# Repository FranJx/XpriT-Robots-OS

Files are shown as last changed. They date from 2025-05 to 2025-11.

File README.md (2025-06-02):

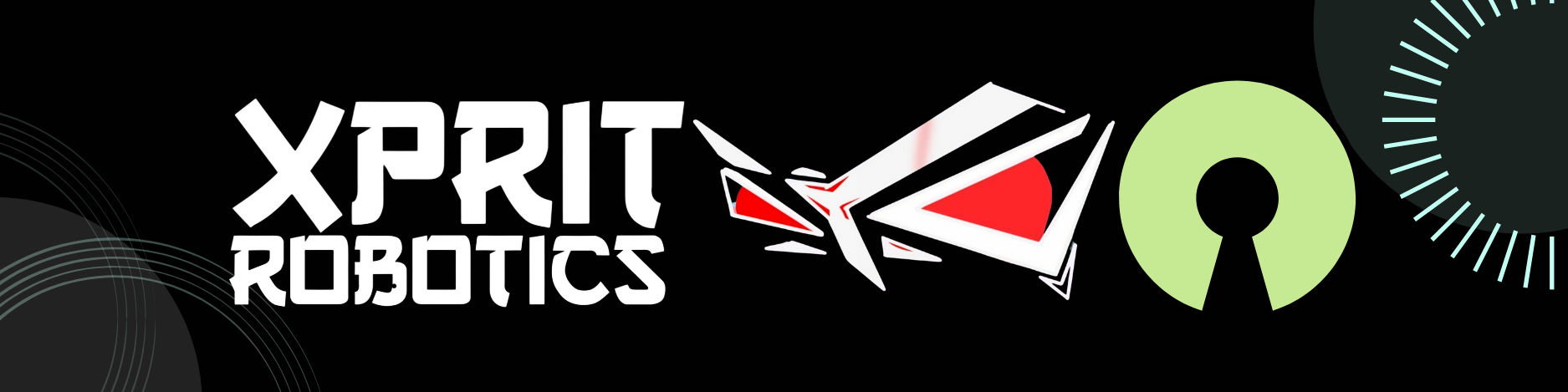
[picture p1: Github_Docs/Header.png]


# ⚙️ XpriT-Robots-OS

Welcome to **XpriT-Robots-OS**, the official collection of projects by **XpriT Robotics**, an Argentine team passionate about competitive, educational, and industrial robotics.

This repository is an open space where we share **complete robots**, **development boards**, **experimental designs**, and much more, aiming to **promote robotics** and inspire the next generation of innovators.

---

## 🌟 About Us

We are a group of young people from Misiones, Argentina, who found in robotics a way to learn, compete, teach, and dream. We founded **XpriT Robotics** with the purpose of taking our ideas beyond competitions, and today we’ve decided to open our designs to the world.

> “We dream of a future where every young person has access to build, make mistakes, gain experience... and share it.”

**Founder:** Franco Joaquín Aguirre Elizalde (Fran)  
🛠️ Self-taught | 🤖 WRO Champion | 🚀 Tech advocate

---

## 📁 Table of Contents

* [🤖 Featured Projects](#-featured-projects)
* [🔧 Boards and Open Hardware](#-boards-and-open-hardware)
* [📦 Repository Structure](#-repository-structure)
* [🧑‍💻 About the Team](#-about-the-team)
* [📸 Gallery and Videos](#-gallery-and-videos)
* [📜 Licenses](#-licenses)
* [📲 Social Media & Contact](#-social-media--contact)

---

## 🤖 Featured Projects

### 🐍 **Kōryū** — The Dragon of Wisdom
> This robot was developed to meet every need a minisumo might have. It's both fast and powerful, offering a perfect balance between speed and strength. Kōryū features an interactive OLED interface and multiple operating modes, including both Autonomous and RC (Remote Control) functionality.  
> In this project you'll find:
> - STL and SLDPRT of the chassis
> - Modular code with multi-mode support
> - Strategy breakdown and competition videos

---

### ⚔️ **XT Kaisei** — Precision in Minisumo Form

> Designed for **both beginners and professionals**, XT Kaisei delivers reliable performance in a compact and modular build. Its balanced sensor array and flexible motor support allow for efficient targeting, quick response, and seamless upgrades.  
> Includes:  
> - 98×98 mm 3D printable chassis  
> - 5x JS40F object sensors + 2x QTR1A line sensors  
> - Dual motor brackets for 050 or N20 formats

---

### 🛡️ **Titan-Core** — The XpriT All-Terrain Base

> Our foundational design for testing, learning, and continuous evolution.  
> Perfect for those who want to understand how a combat robot is built from scratch.  
> Contains:
> - Commented and modular code  
> - Custom PCB  
> - Step-by-step explanation

> ⚙️ More designs will be added: the XpriT collection never stops growing!

---

## 🔧 Boards and Open Hardware

This section includes our **custom-designed boards for competitive and educational robotics**:

- **XT-Prime**: ESP-based board with x3dipswitch, 9 GPIO( support I2C), 14v10A drivers x2 and 2A regulator  
- **XT-Pyramis**: A tiny Arduino-Based board for Autonomous Sumo( mini - micro) robots  
- **XP-SimDrive**: ESP32 + TB6612FNG Shield for simple RC robots

Each board includes:
- Gerber files + PDF  
- Component list  
- STL for protective casing  
- Schematics + technical documentation

---

## 🧑‍💻 About the Team

Team

We are **Franco**, **Marcelo**, **Franquito**, **Benja**, **Bauti**, and a group of collaborators, mentors, and friends who joined this journey. Our experience includes:

- 🥉 19th place at RoboChallenge Romania 2024  
- 🥇 National Champion at WRO Panama 2023  
- 🥉 3rd place at National Minisumo PRO 2023  
- 🏆 Multiple podiums at Robotic People Fest, Copa Robótica Misiones, and more

XpriT Robotics is more than a team: we are a growing and learning community.

---

## 📸 Gallery and Videos

Find photos of our robots and real demos at:

- 📷 Folder [`Images`](./Images)  
- 📽️ YouTube Channel [@xprit_robotics](https://youtube.com/@xprit_robotics)

> Subscribe so you don’t miss our next creations!

---

## 📜 Licenses

All our projects are released under licenses that allow free use with proper credit:

- **Code** → [MIT License](./LICENSE)  
- **3D designs, boards, and documentation** → [CC BY 4.0](https://creativecommons.org/licenses/by/4.0/)

> 🛡️ Use them, improve them — and don’t forget to credit us!

---

## 📲 Social Media & Contact

- 📸 Instagram: [@xprit_._robotics](https://www.instagram.com/xprit_robotics/)  
- ▶️ YouTube: [@xprit robotics](https://youtube.com/@xprit_robotics)  
- 📧 Contact: xpritrobotics@gmail.com

---

**Thanks for visiting our repository.**  
**Let’s keep building, competing, and sharing robotics!**

> Made with 💙 in Misiones, Argentina by XpriT Robotics.

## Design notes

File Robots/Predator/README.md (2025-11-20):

# 🤖 Predator - Mini Sumo Autónomo Profesional

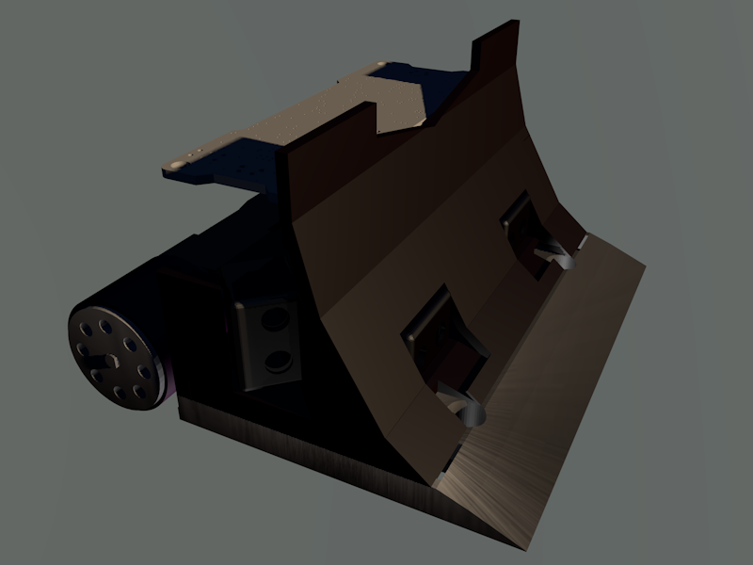
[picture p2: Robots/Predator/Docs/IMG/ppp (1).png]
Predator Robot


## Descripción General

**Predator** es un robot Mini Sumo Autónomo de clase profesional, diseñado por **Marcelo D. Benítez**, co-líder de **XpriT Robotics**. Este robot ha participado en numerosas competencias de robótica autónoma, obteniendo satisfactorios resultados en las categorías de mini sumo.

Predator combina ingeniería mecánica de precisión, electrónica avanzada y algoritmos de reacción rápida para crear una máquina competitiva capaz de detectar, perseguir y empujar adversarios fuera del ring de competencia con efectividad.

### Características Principales

- ⚡ **Sistema de 4 sensores**: Detecta adversarios en múltiples direcciones
- 🎯 **Lógica de ataque**: Búsqueda y persecución automática
- 🔋 **Autonomía**: Duración completa de competencia (5 minutos de ronda)
- 🛠️ **Diseño optimizado**: Tras múltiples iteraciones competitivas
- 📐 **Dimensiones competitivas**: Dentro de especificaciones oficial
- 💪 **Motor diferencial**: Control de giros precisos y empuje

## Especificaciones Técnicas

### Hardware

| Parámetro | Valor |
|---|---|
| Microcontrolador | Placa Xmotion Jsumo (Arduino Leonardo) |
| Sensores de Oponente | 4 (IR JS40F - rango ~40cm) |
| Sensores de Línea | 2 (Sensor ML1) |
| Motores | 2x Jsumo 750RPM @ 6V |
| Ruedas | JS2622 (26mm diámetro) |
| Batería | LiPo 3S 350mAh 11.1V |
| Sistema de Movimiento | Motor diferencial (tracción dual) |
| Botón de inicio | Cuenta regresiva 5s antes de competencia |
| Indicadores | 2 LEDs (naranja: espera, azul: countdown) |

### Especificaciones de Rendimiento

**A 12V (alimentación real con LiPo 3S):**

| Parámetro | Valor |
|---|---|
| RPM (teórico) | 1500 RPM |
| Velocidad lineal máxima | 204 cm/s (2.04 m/s) |
| Velocidad en km/h | 7.35 km/h |
| Velocidad angular (rueda) | 157.08 rad/s |
| Velocidad de giro (robot) | 2925 °/s (51.05 rad/s) |
| Pines digitales | 8 |
| Pines analógicos | 2 |
| Velocidades PWM | 0-255 |
| Velocidad búsqueda | 30 PWM (configurable) |

## 📦 Contenido del Repositorio

```
Predator/
├── README.md                    # Este archivo
├── LICENCIA.md                  # Licencia de código abierto
├── src/
│   └── predator.ino             # Firmware principal del robot
├── Docs/
│   ├── IMG/                     # Fotografías del robot en acción
│   │   ├── ppp (1).png
│   │   └── ppp (2).png
│   └── Componentes.docx         # Lista de componentes
└── STL/                         # Archivos para impresión 3D
    ├── base.stl
    ├── bracket.stl
    └── chasis.stl
```

## 🏆 Logros y Participaciones

- ✅ Múltiples participaciones en competencias Mini Sumo profesionales
- ✅ Diseño robusto tras 7+ generaciones de prototipo
- ✅ Algoritmo de búsqueda y ataque refinado en campo real
- ✅ Sistema de seguridad de línea efectivo y rápido

## 🎯 Algoritmo de Comportamiento

Predator utiliza una máquina de estados reactiva con 4 sensores de oponente:

### Lógica de Detección (4 sensores)

```
Sensor Derecha         → Detección lateral derecha (A2)
Sensor Diagonal Der    → Detección 45° derecha (A4)
Sensor Diagonal Izq    → Detección 45° izquierda (pin 2)
Sensor Izquierda       → Detección lateral izquierda (pin 1)
```

**Sensores de línea (borde de pista):**
- Línea Izquierda (A5) → Detecta borde blanco
- Línea Derecha (A1) → Detecta borde blanco

### Estados de Comportamiento

| Estado | Acción | Condición |
|---|---|---|
| **IDLE** | Inmóvil, LED naranja | Esperando botón |
| **COUNTDOWN** | Parpadeo azul 5s | Cuenta regresiva antes de competencia |
| **RUN** | Búsqueda o ataque | Competencia en curso |

### Lógica de Ataque

1. **Si detecta en ambos lados** → Atacar de frente (máxima velocidad: 255)
2. **Si detecta solo derecha** → Girar a derecha (velocidad 255/-255)
3. **Si detecta solo izquierda** → Girar a izquierda (velocidad -255/255)
4. **Si no detecta nada** → Búsqueda lenta (velocidad ~30)

### Seguridad de Línea

Si el robot detecta que está saliendo del ring:
- Retrocede a velocidad 120
- Gira 90° para alejarse del borde
- Retoma búsqueda automáticamente

## 🖼️ Galería

### Predator en Acción

Predator Robot - Vista 1

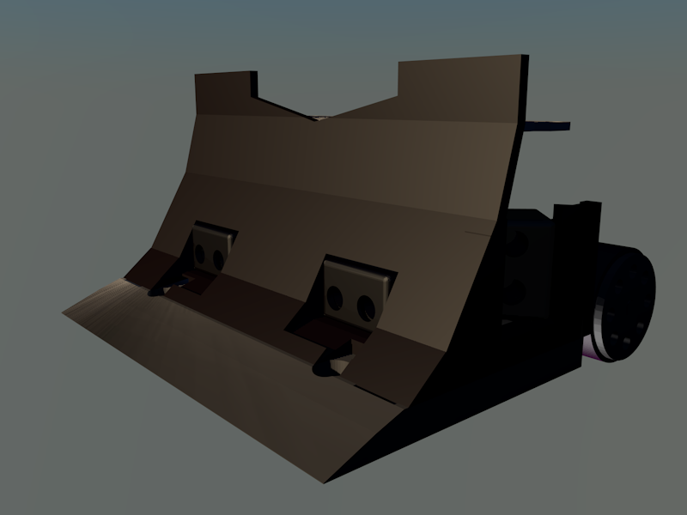
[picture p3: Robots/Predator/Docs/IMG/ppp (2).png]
Predator Robot - Vista 2


## 💻 Código Fuente

El firmware de Predator está desarrollado en **C/C++** para Arduino, utilizando la librería **xmotion** para control de motores.

### Estructura Principal

```cpp
// SENSORES DE OPONENTE (4 puntos de detección)
int RightSensor         = A2;  // Derecha
int RightDiagonalSensor = A4;  // Diagonal derecha
int LeftDiagonalSensor  = 2;   // Diagonal izquierda
int LeftSensor          = 1;   // Izquierda

// SENSORES DE LÍNEA (Seguridad de borde)
int LeftLine  = A5;   // Línea izquierda
int RightLine = A1;   // Línea derecha

// CONTROLES
const int StartPin   = 10;  // Botón de inicio
const int LedNaranja = 8;   // LED de espera
const int LedAzul    = 9;   // LED de cuenta regresiva
```

### Máquina de Estados

El robot opera en 3 estados principales:

1. **IDLE**: Esperando que presionen botón (LED naranja fijo)
2. **COUNTDOWN**: Cuenta regresiva de 5 segundos (LED azul parpadeando)
3. **RUN**: En competencia (LEDs apagados)

### Lógica de Comportamiento

```cpp
// Prioridades de ataque:
if (detecta_ambos_lados) {
  atacar_de_frente();      // Velocidad máxima (255, 255)
} 
else if (detecta_derecha) {
  girar_a_derecha();       // Velocidad (-255, 255)
} 
else if (detecta_izquierda) {
  girar_a_izquierda();     // Velocidad (255, -255)
} 
else {
  buscar_lentamente();     // Velocidad (~30, ~30)
}

// Protección de línea:
if (sensor_linea_activo) {
  retroceder_y_girar();    // Velocidad (-120), giro 90°
}
```

### Variables Configurables

```cpp
// Velocidad de búsqueda (0-255)
int velBusqueda = 30;  // Ajustar según tatami

// Umbral de detección de línea
const int UMBRAL_LINEA = 700;  // Valores analógicos

// Antirrebote del botón
const unsigned long DEBOUNCE_MS = 30;  // milisegundos
```

### Compilación y Carga

```bash
# Abrir en Arduino IDE
1. Archivo → Abrir → src/predator.ino
2. Seleccionar placa: Arduino Leonardo
3. Seleccionar puerto COM
4. Cargar (Ctrl+U)
```

**Requisitos:**
- Arduino IDE instalado
- Librería `xmotion` disponible
- Placa Arduino Leonardo o compatible

## ⚙️ Configuración y Ajustes

### Parámetros Ajustables

Los siguientes parámetros pueden modificarse en `src/predator.ino` según tu tatami y preferencias:

#### Velocidades (0-255)

```cpp
int velBusqueda = 30;  // Velocidad de búsqueda
                       // Aumentar para buscar más rápido
                       // Reducir para búsqueda cautelosa
```

#### Umbrales de Línea

```cpp
const int UMBRAL_LINEA = 700;  // Valor para detectar línea blanca
                                // Probar en el tatami real
                                // Valores típicos: 600-800
```

#### Antirrebote

```cpp
const unsigned long DEBOUNCE_MS = 30;  // Tiempo antirrebote botón
```

### Calibración en el Tatami

1. **Ajustar velocidad de búsqueda**
   - Si el robot es muy lento: aumentar `velBusqueda`
   - Si es muy rápido: reducir `velBusqueda`

2. **Calibrar detectores de línea**
   - Poner sensor sobre línea blanca
   - Leer valor analógico con Serial Monitor
   - Ajustar `UMBRAL_LINEA` según sea necesario

3. **Probar velocidades de giro**
   - Valores actuales: ±255 giros máximos
   - ±100 giros suaves
   - Ajustar según respuesta deseada

## 🛠️ Mantenimiento y Reparación

### Antes de Cada Competencia

- [ ] Verificar que el botón responde correctamente
- [ ] Probar LED naranja y LED azul
- [ ] Limpiar lentes de sensores IR
- [ ] Verificar que los motores responden a comandos
- [ ] Revisar tensión correcta entre ruedas (no muy apretadas)
- [ ] Cargar batería completamente

### Solución de Problemas Comunes

**El robot no se mueve**
- Verificar conexión de batería
- Comprobar que Arduino cargó el firmware
- Usar Serial Monitor para debug (9600 baud)

**El robot tuerce a un lado**
- Motor derecho e izquierdo pueden tener potencias diferentes
- Ajustar velocidades en los giros
- Revisar si las ruedas están alineadas

**No detecta al oponente**
- Revisar que sensores no están sucios o bloqueados
- Verificar lecturas analógicas en Serial Monitor
- Probar que los sensores devuelven 0 (detectan) cuando activan

**Se cae del ring**
- Revisar umbral de línea en código
- Probar que sensores de línea funcionan
- Calibrar `UMBRAL_LINEA` en el tatami real

### Piezas de Repuesto Comúnmente Requeridas

- Llantas (desgaste de competencia)
- Sensores (golpes o desconexiones)
- Conectores y cables (tracción o daño)
- Piezas impresas (fracturas por impacto)

## 🤝 Contribuciones

Las contribuciones son bienvenidas. Por favor:

1. Fork el repositorio
2. Crea una rama para tu mejora (`git checkout -b feature/MiMejora`)
3. Commit tus cambios (`git commit -m 'Agregar MiMejora'`)
4. Push a la rama (`git push origin feature/MiMejora`)
5. Abre un Pull Request

## 📚 Referencias y Recursos

- [Pagina Oficial de XpriT Robotics](http://xprit-robotics.com/)
- [Pagina de Instagram p/ consultas](https://www.instagram.com/xprit_robotics/)

## 📊 Bill of Materials (BOM)

Para la lista completa actualizada, ver `Docs/Componentes.md`

| Componente | Cantidad | Enlace |
|---|---|---|
| Placa Xmotion | 1 | [JsumoRobots](https://www.jsumo.com/xmotion-robot-controller) |
| Motores Jsumo 750RPM | 2 | [JsumoRobots](https://www.jsumo.com/core-dc-motor-6v-750rpm) |
| Sensores JS40F (IR) | 4 | [JsumoRobots](https://www.jsumo.com/js40f-digital-infrared-ir-distance-sensor-min-40-cm-range) |
| Ruedas JS2622 (Par) | 1 | [JsumoRobots](https://www.jsumo.com/js2622-aluminum-silicone-wheel-pair) |
| Sensores Línea ML1 | 2 | [JsumoRobots](https://www.jsumo.com/micro-line-sensor-ml1) |
| Batería LiPo 3S 350mAh | 1 | - |

**Proveedor principal:** [JsumoRobots](https://www.jsumo.com/) - Todos los componentes electrónicos disponibles en este sitio.

## 🎯 Roadmap Futuro

### Versión 1.1
- [ ] Optimización de velocidades basada en tatami
- [ ] Mejora de algoritmo de búsqueda
- [ ] Documentación de calibración completa

### Versión 2.0 (Futuro)
- [ ] Integración de sensores ultrasónicos
- [ ] Sistema mejorado de detección multirrango
- [ ] Modo de radio control remoto para debug
- [ ] Telemetría en tiempo real

### Ideas de Mejora
- Detectores de colisión para absorber impactos
- Sistema de peso distribuido optimizado
- Variante con mayor potencia de motor
- Interfaz de configuración inalámbrica

## ⚖️ Licencia

Este proyecto está bajo la **Licencia de Código Abierto por Mención de Autor**.

Ver `LICENCIA.md` para términos completos y legales.

```
Predator Robot - Mini Sumo Autónomo Profesional
Diseño original: Marcelo D. Benítez
Organización: XpriT Robotics
Licencia: Código Abierto por Mención de Autor
Año: 2024-2025
```

## 📞 Contacto y Soporte

- **Diseñador**: Marcelo D. Benítez (co-líder XpriT Robotics)
- **Organización**: [XpriT Robotics](https://xpritrobotics.org)
- **Email**: contact@xpritrobotics.org
- **Issues y Soporte**: GitHub Issues en este repositorio

---

**Predator Robot** © 2024-2025 XpriT Robotics  
Licencia: Código Abierto por Mención de Autor

*Última actualización: Noviembre 20, 2025*

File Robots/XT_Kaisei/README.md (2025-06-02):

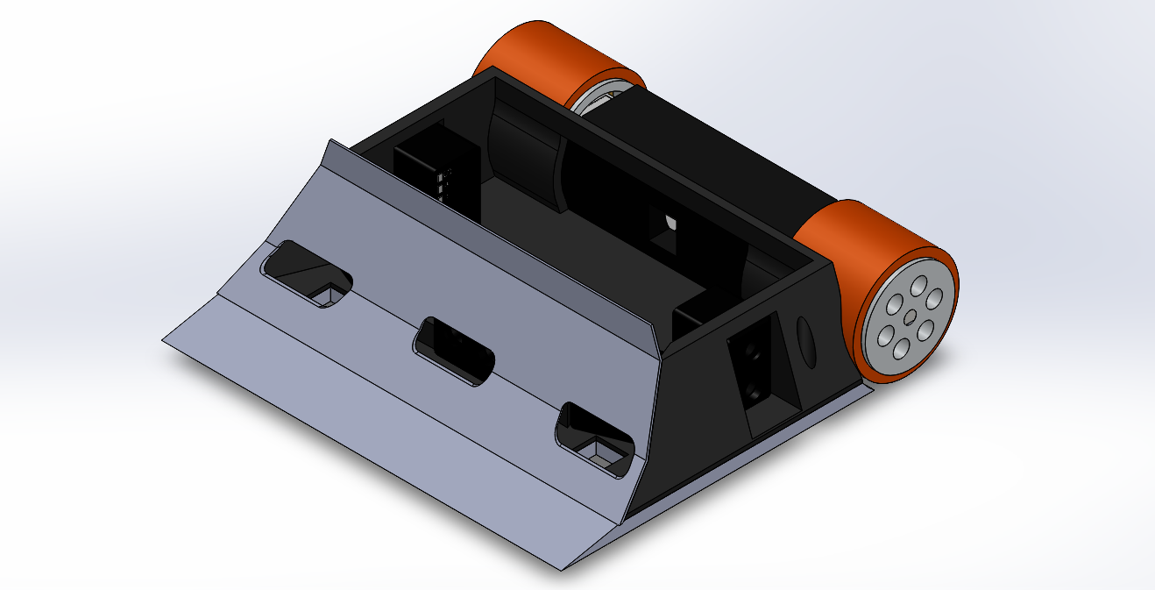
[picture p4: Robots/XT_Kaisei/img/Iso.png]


# ⛩️ XT Kaisei - Open-Source Minisumo Robot by XpriTRobotics

**KAISEI** is a **professional minisumo robot** designed for both **beginners** and **advanced users**. Equipped with everything a robot needs to stand out in the ring, it's perfect for learning robotics or as a solid base to build a high-performance sumo project.

---

## 📸 Image Gallery

| View | Image |
|---|---|
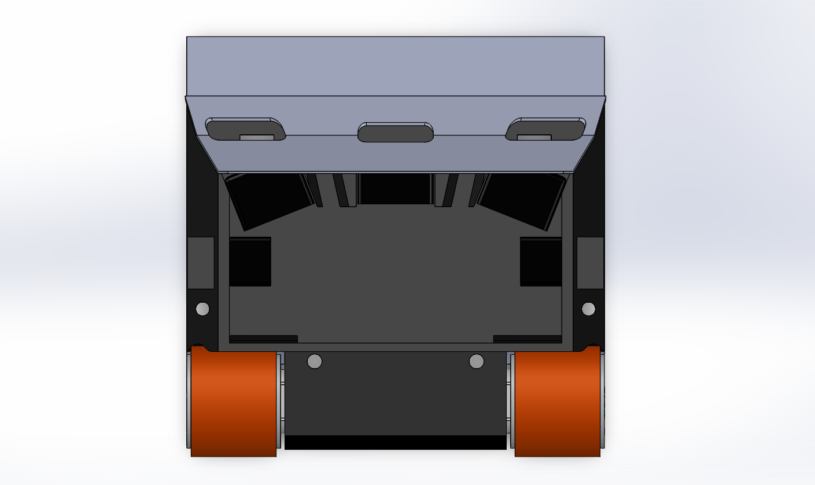
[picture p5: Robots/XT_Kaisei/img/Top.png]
| Top |  |
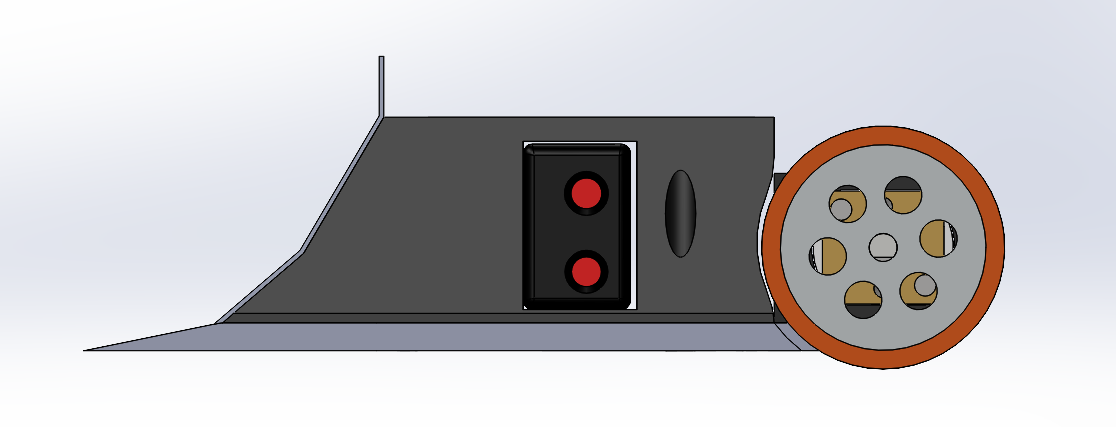
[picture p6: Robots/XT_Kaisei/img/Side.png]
| Side |  |
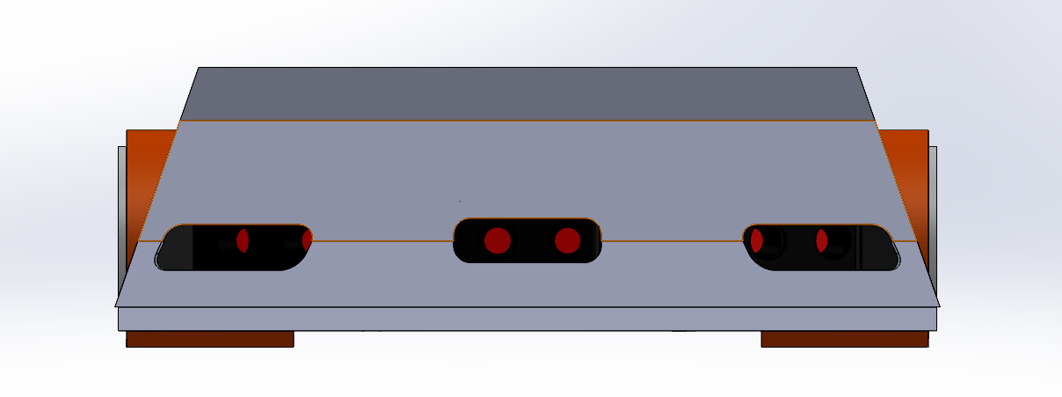
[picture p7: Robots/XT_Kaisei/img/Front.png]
| Front |  |
| Isometric |  |
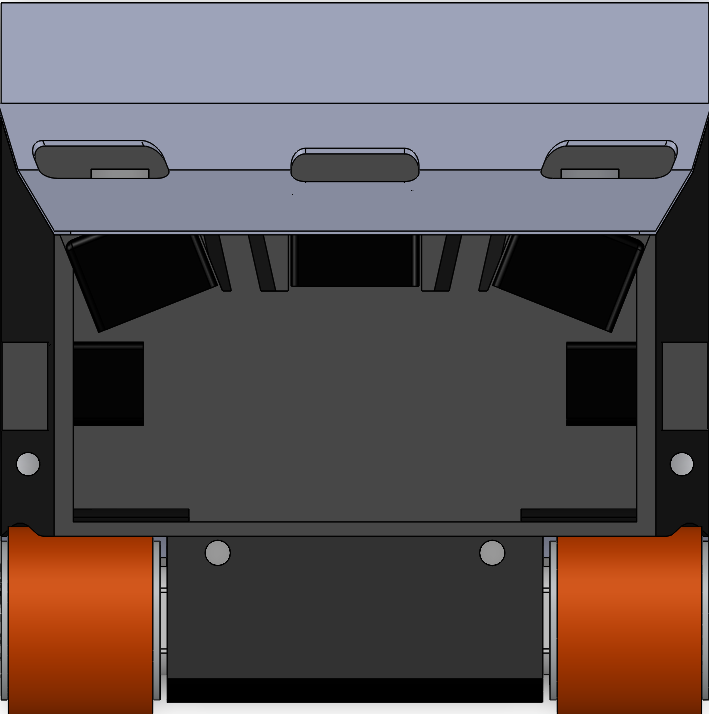
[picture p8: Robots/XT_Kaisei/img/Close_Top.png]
| Close Top |  |

---

## ⚙️ Technical Specifications

| Feature | Description |
|---|---|
| Dimensions | 98mm x 98mm |
| Weight | ~370g (depends on base material) |
| Enemy detection sensors | 5x JS40F |
| Line sensors | 2x QTR1A |
| Supported motor types | 050 (Jsumo/Sobotz) or N20 (Pololu, etc.) |
| Motor brackets | Available for 050 and N20 motors |
| Battery recommendation | Ministar 350mAh 3S LiPo |
| Base structure | Customizable (3D printed or other) |
| Mainboard compatibility | Universal |

---

## 🧠 Compatible Boards

KAISEI supports **virtually any board** that physically fits. However, it is optimized for **Xprit's own boards**.

| Board / MCU | Compatibility | Notes |
|---|---|---|
| Xprit Boards | ✅ | Native support recommended |
| Arduino UNO/Nano | ✅ | Fully compatible |
| ESP32 | ✅ | Great for wireless functionality |
| STM32 | ✅ | |
| Raspberry Pi Pico  | ✅ | |

---

## 💻 Programming

Programming depends on the chosen microcontroller. KAISEI supports:

- Arduino IDE (C/C++)
- PlatformIO
- MicroPython (on supported boards)
- Other environments as needed

**Common Examples**:
- Enemy detection with JS40F 
- Attack and retreat strategies

> Example files will be available soon in the `/code/` folder.

---

## 📦 Components List

| Component | Suggested Model / Brand | Quantity |
|---|---|---|
| Object sensors | JS40F | 5 |
| Line sensors | QTR1A | 2 |
| Motors | 050 (Jsumo/Sobotz) or N20 (Pololu) | 2 |
| Motor drivers | JS2622 or compatible | 2 |
| Battery | Ministar 350mAh 3S LiPo | 1 |
| Mainboard | Compatible board (Xprit, etc.) | 1 |
| Chassis | 3D printed or custom | 1 |

---

## 📂 Project Structure

```plaintext
KAISEI/
├── README.md
├── img/
│   ├── Top.jpg
│   ├── Side.jpg
│   ├── Front.jpg
│   ├── Iso.jpg
│   └── Close_Top.jpg
├── code/
│   └── [Upcoming example files]
├── docs/
│   └── [Assembly guides, coming soon]
└── stl/
│   └── [3D printable files]
└── SLDPRT/
    └── [Solid Works Parts]

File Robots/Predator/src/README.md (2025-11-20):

# Código Fuente - Predator Robot

Este directorio contiene el firmware (código) principal de Predator.

## Archivo Principal

### 📄 predator.ino

Firmware completo de Predator Robot desarrollado en C/C++ para Arduino.

**Requisitos:**
- Arduino IDE (descarga gratuita en arduino.cc)
- Librería `xmotion` para control de motores
- Placa Arduino Leonardo o compatible

**Contenido:**
- Configuración de pines de sensores
- Máquina de estados (IDLE, COUNTDOWN, RUN)
- Lógica de detección de oponentes
- Lógica de seguridad de línea
- Funciones de control de LEDs
- Funciones de detección de botón

## Cómo Compilar y Cargar

### En Arduino IDE

1. **Abrir el archivo:**
   - Ir a Archivo → Abrir
   - Seleccionar `predator.ino`

2. **Configurar placa:**
   - Herramientas → Placa → Arduino Leonardo
   - Herramientas → Puerto → Seleccionar puerto COM

3. **Compilar:**
   - Presionar Ctrl+R o Verificar/Compilar

4. **Cargar:**
   - Presionar Ctrl+U o Upload
   - Esperar a que se complete

### En Línea de Comandos (Arduino CLI)

```bash
# Compilar
arduino-cli compile --fqbn arduino:avr:leonardo .

# Cargar
arduino-cli upload -p COM3 --fqbn arduino:avr:leonardo .
```

## Estructura del Código

```
┌─ CONFIGURACIÓN
│  ├─ Pines de sensores
│  ├─ Pines de controles
│  └─ Variables globales
│
├─ FUNCIONES AUXILIARES
│  ├─ Detección de botón
│  ├─ Control de LEDs
│  └─ Seguridad de línea
│
├─ SETUP()
│  ├─ Inicialización de pines
│  ├─ Configuración serial
│  └─ Estado inicial
│
└─ LOOP()
   ├─ Lectura de botón
   ├─ Máquina de estados
   └─ Control de motores
```

## Parámetros Configurables

### Velocidad de Búsqueda

```cpp
int velBusqueda = 30;  // Cambiar entre 0-255
```

Aumentar para búsqueda rápida, reducir para cautelosa.

### Umbral de Línea

```cpp
const int UMBRAL_LINEA = 700;  // Valores típicos 600-800
```

Calibrar según tu tatami real.

### Tiempo de Antirrebote

```cpp
const unsigned long DEBOUNCE_MS = 30;  // Milisegundos
```

### Pines de Sensores

```cpp
int RightSensor         = A2;   // Derecha
int RightDiagonalSensor = A4;   // Diagonal derecha
int LeftDiagonalSensor  = 2;    // Diagonal izquierda
int LeftSensor          = 1;    // Izquierda
int LeftLine            = A5;   // Línea izquierda
int RightLine           = A1;   // Línea derecha
```

### Pines de Control

```cpp
const int StartPin   = 10;  // Botón de inicio
const int LedNaranja = 8;   // LED indicador reposo
const int LedAzul    = 9;   // LED cuenta regresiva
```

## Debugging

### Serial Monitor

Para ver mensajes de debug, abrir Serial Monitor (9600 baud):

```
Herramientas → Serial Monitor
```

O agregar código para imprimir valores:

```cpp
Serial.print("Sensor IR: ");
Serial.println(sR);
```

## Máquina de Estados

El robot opera en 3 estados:

### IDLE (Espera)
- LED naranja encendido
- Esperando que presionen el botón
- Motores detenidos

### COUNTDOWN (Cuenta Regresiva)
- LED azul parpadeando 5 segundos
- Preparando competencia
- Transición a RUN después

### RUN (Competencia)
- LEDs apagados
- Buscando y atacando adversarios
- Detectando bordes

## Lógica de Ataque

```
SI detecta en ambos lados → Atacar de frente
SINO SI detecta derecha → Girar derecha
SINO SI detecta izquierda → Girar izquierda
SINO → Buscar lentamente
```

Si detecta línea → Retroceder y girar

## Velocidades

```
Ataque máximo (ambos sensores):  255, 255
Giro fuerte derecha:           -255, 255
Giro fuerte izquierda:          255, -255
Corrección suave derecha:       -100, 255
Corrección suave izquierda:      255, -100
Búsqueda lenta:                  ~30,  ~30
Retroceso defensa:             -120, -120
```

## Notas Importantes

1. **Librería xmotion**: Debe estar instalada en Arduino IDE
2. **Velocidades PWM**: 0-255, donde 255 es máxima
3. **Sensores**: Retornan 0 cuando detectan, 1 cuando no
4. **Línea blanca**: UMBRAL_LINEA debe ser >700 para detectarla
5. **Botón**: INPUT_PULLUP, activa en flanco de subida

## Modificaciones Comunes

### Cambiar velocidad de búsqueda

```cpp
// Línea 17 - cambiar de 30 a otro valor
int velBusqueda = 50;  // Más rápido
```

### Cambiar velocidad de ataque

Línea 149 en comportamiento RUN:
```cpp
xmotion.MotorControl(255, 255);  // Cambiar 255 a otro valor
```

### Agregar Serial Debug

En setup():
```cpp
Serial.begin(9600);
```

En loop():
```cpp
Serial.print("Estado: ");
Serial.println(estado);
```

---

Para más información, consultar el README principal.

**Última actualización**: Noviembre 20, 2025

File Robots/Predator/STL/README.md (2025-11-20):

# Modelos 3D - Predator Robot

Esta carpeta contiene los archivos STL (Stereolithography) para impresión 3D de las piezas estructurales del robot Predator.

## Archivos STL

### 📄 chasis.stl
Estructura principal del robot (chassis).
- Contiene montajes de motores
- Alojamiento de electrónica
- Conexiones estructurales

### 📄 base.stl
Base de soporte.
- Plataforma principal
- Distribuye peso

### 📄 bracket.stl
Soporte/bracket (puede ser para sensores, cables u otros).
- Accesorio de montaje
- Componente modular

## Cómo Imprimir

### Software Recomendado
- Cura (gratuito)
- PrusaSlicer (gratuito)
- Simplify3D (pago)

### Parámetros de Impresión Sugeridos

**Material**: PETG o ABS recomendados
- PLA también funciona, pero es más frágil
- PETG ofrece mejor resistencia a impactos

**Configuración**:
- Resolución (Layer Height): 0.2mm
- Relleno (Infill): 15-20%
- Velocidad: 50-60 mm/s
- Temperatura:
  - PETG: 230-240°C
  - ABS: 230-240°C
  - PLA: 200-210°C

**Soportes**: 
- Usar soportes donde sea necesario
- Generar automáticamente en slicer

**Placa de impresión**:
- Usar adhesivo o hairspray
- PETG necesita superficie caliente (70-80°C)

## Tiempo de Impresión Estimado

| Pieza | Tiempo | Peso |
|---|---|---|
| chasis.stl | 8-12h | 80-120g |
| base.stl | 3-5h | 30-50g |
| bracket.stl | 1-2h | 10-15g |
| **Total** | **12-19h** | **120-185g** |

## Guía de Uso

### 1. Descargar Archivo

- Descargar .stl a tu computadora

### 2. Abrir en Slicer

- Abrir software de slicing (Cura, etc.)
- Importar archivo STL
- Escala: Usar tamaño original (100%)

### 3. Verificar Orientación

- Pieza debe estar orientada para máxima estabilidad
- Usar vista previa para verificar
- Ajustar si es necesario

### 4. Generar Soportes

- Software generará automáticamente
- Revisar que no haya mucho material de soporte

### 5. Exportar G-code

- Generar archivo G-code para impresora
- Copiar a memoria SD o enviar por USB

### 6. Imprimir

- Cargar filamento
- Calentar placa y hot-end
- Comenzar impresión
- Monitorear primeras capas

### 7. Post-Procesamiento

- Remover soportes con cuidado
- Lijar bordes ásperos (papel 120-220)
- Limpiar residuos de filamento

## Calibración de Tolerancias

Si las piezas no encajan bien:

1. **Demasiado apretadas**:
   - Aumentar tamaño de agujeros en CAD
   - O lijar suavemente

2. **Muy sueltas**:
   - Usar pegamento (cianoacrilato) si es permanente
   - O usar tuerca-vástago para montaje ajustable

## Reemplazo de Piezas

Si una pieza se daña:

1. Anotar dimensiones de la dañada
2. Descargar STL original
3. Modificar en CAD si es necesario
4. Reimprimir siguiendo pasos anteriores

## Almacenamiento

Conservar archivos STL en:
- Dispositivo de almacenamiento local
- Nube (Google Drive, OneDrive, etc.)
- Repositorio GitHub

## Mejoras y Modificaciones

Si necesitas personalizar las piezas:

### Software de Modelado 3D (Gratuito)
- Fusion 360 (limitado gratis)
- FreeCAD (completamente gratis)
- Tinkercad (en línea, gratis)
- Blender (gratuito, complejo)

### Pasos para Modificar

1. Descargar STL
2. Importar en software CAD
3. Realizar cambios (agujeros, soportes, etc.)
4. Exportar como STL nuevo
5. Imprimir versión modificada

## Troubleshooting de Impresión

**Capas no se adhieren**:
- Limpiar placa
- Aumentar temperatura
- Reducir altura de capa

**Piezas deformadas**:
- Aumentar relleno
- Mejorar ventilación del hot-end
- Usar material con mejor temperatura

**Agujeros tapiados**:
- Aumentar altura de capa
- Usar soportes en agujeros

**Bordes ásperos**:
- Esto es normal en FDM
- Lijar después de imprimir

## Proveedores de Servicios de Impresión

Si no tienes impresora 3D:

| Servicio | País | Características |
|---|---|---|
| Shapeways | Mundial | Múltiples materiales |
| Sculpteo | Europa | Buena calidad |
| Thingiverse Printify | Mundial | Económico |
| Tienda Local | Tu ciudad | Soporte local |

## Especificaciones de Archivo

```
Formato: STL (ASCII o Binary)
Escala: Milímetros (mm)
Unidades: 1 STL unit = 1 mm
```

---

Para más información, consultar el README principal.

**Última actualización**: Noviembre 20, 2025

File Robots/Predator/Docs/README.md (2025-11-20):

# Documentación - Predator Robot

Esta carpeta contiene la documentación adicional y recursos para Predator Robot.

## Contenido

### 📄 Componentes.docx
Lista completa de componentes utilizados en Predator, incluyendo:
- Referencias de compra
- Especificaciones técnicas
- Proveedores recomendados
- Precios aproximados

### 📸 IMG/
Fotografías del robot Predator:
- `ppp (1).png` - Vista del robot
- `ppp (2).png` - Vista alternativa del robot

## Próximamente

Esta sección se expandirá con:
- Manuales de ensamblaje detallado
- Guías de calibración
- Esquemas eléctricos
- Diagramas de conexionado
- Fotografías de proceso de construcción

---

Para más información, consultar el README principal.

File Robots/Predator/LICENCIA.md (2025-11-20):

# Licencia de Código Abierto por Mención de Autor

## Predator Robot - Mini Sumo Autónomo Profesional

**Proyecto**: Predator Robot  
**Diseñador Original**: Marcelo D. Benítez  
**Organización**: XpriT Robotics  
**Año**: 2024-2025  
**Versión de Licencia**: 1.0

---

## 📜 Resumen Ejecutivo

Predator Robot es código abierto bajo la licencia **"Atribución-CompartirIgual"**. Puedes usar, modificar y distribuir libremente el código y diseños siempre que:

1. ✅ **Menciones explícitamente** a Marcelo D. Benítez como diseñador original
2. ✅ **Menciones explícitamente** a XpriT Robotics como creador
3. ✅ **Mantengas** esta licencia en distribuciones derivadas
4. ✅ **No uses** la marca XpriT Robotics sin autorización expresa

---

## 1. TÉRMINOS Y CONDICIONES

### 1.1 Derechos Otorgados

Se otorga por este medio una licencia mundial, libre de regalías, no exclusiva e irrevocable para:

- ✅ Usar el diseño (STL), código fuente y documentación
- ✅ Modificar y adaptar para necesidades específicas
- ✅ Fabricar, construir y ensamblar robots basados en Predator
- ✅ Distribuir copias del código y documentación
- ✅ Utilizar en competencias, educación e investigación
- ✅ Crear derivados y mejoras

### 1.2 Requisitos Obligatorios

Para ejercer los derechos anteriores, **DEBES**:

1. Mencionar explícitamente a **Marcelo D. Benítez** como diseñador original
2. Mencionar explícitamente a **XpriT Robotics** como organización creadora
3. Mantener esta licencia en todas las distribuciones
4. Indicar qué cambios realizaste a la versión original (si aplica)

### 1.3 Ejemplo de Atribución Correcta

```
Predator Robot
Diseño original por Marcelo D. Benítez (XpriT Robotics)
Basado en: https://github.com/XpriT-Robotics/Robots-OS
Esta versión incluye [describir tus cambios]
Licencia: Código Abierto por Mención de Autor
```

---

## 2. RESTRICCIONES

### 2.1 Lo que NO está permitido

❌ **NO puedes:**
- Reclamar autoría del diseño original
- Ocultar o negar el origen de Predator
- Remover avisos de copyright o licencia
- Comercializar afirmando ser el diseñador original
- Usar la marca "XpriT Robotics" sin autorización
- Afirmar que Marcelo D. Benítez te respalda sin consentimiento

### 2.2 Comercialización

Puedes:
- ✅ Vender robots construidos con Predator
- ✅ Ofrecer servicios de construcción/calibración
- ✅ Vender mejoras y componentes

Pero **SIEMPRE debes** dar crédito explícito al diseñador original.

---

## 3. DERIVADOS Y MODIFICACIONES

Si creas un derivado (versión modificada) de Predator:

1. Indicar claramente qué cambiaste
2. Distribuir bajo la **misma licencia**
3. Dejar constancia del trabajo original de Marcelo D. Benítez
4. Hacer disponible el código/diseño modificado

### Ejemplo Correcto

```
Predator v1.1 - Mejora de sensores

Basado en: Predator Robot por Marcelo D. Benítez (XpriT Robotics)

Cambios:
- Reemplazo de sensores por versión mejorada
- Optimización de algoritmo de búsqueda
- [tus otros cambios]

Licencia: Código Abierto por Mención de Autor
```

---

## 4. GARANTÍA Y DISCLAIMERS

### 4.1 AUSENCIA DE GARANTÍA

Este software y diseño se proporciona **"TAL COMO ESTÁ"**, sin garantía de ningún tipo.

No hay garantía de:
- Comerciabilidad
- Aptitud para un propósito particular
- Funcionamiento correcto bajo todas las condiciones

### 4.2 Limitación de Responsabilidad

**En ningún caso** Marcelo D. Benítez, XpriT Robotics o sus colaboradores serán responsables por:
- Daños directos o indirectos
- Lesiones personales
- Pérdida de datos
- Daño a propiedad tercera

### 4.3 Uso Responsable

El usuario es **responsable** de:
- Cumplir leyes locales
- Usar el robot de forma segura
- Implementar medidas de seguridad
- Verificar funcionamiento antes de competencia
- No causar daño a terceros

---

## 5. ACEPTACIÓN

Al usar, descargar, modificar o distribuir Predator, **aceptas estos términos**.

Si **no aceptas**, no debes usar ni distribuir ningún componente de Predator.

---

## 6. CONTACTO Y AUTORIZACIÓN

Para solicitudes especiales, permisos adicionales o preguntas:

- **Organización**: XpriT Robotics
- **Diseñador**: Marcelo D. Benítez
- **Email**: contact@xpritrobotics.org
- **GitHub**: https://github.com/XpriT-Robotics

---

## 7. FAQ - PREGUNTAS FRECUENTES

**P: ¿Puedo vender robots construidos con Predator?**  
R: Sí, siempre que menciones explícitamente a Marcelo D. Benítez como diseñador original.

**P: ¿Debo pedir permiso para modificar el código?**  
R: No, pero debes mantener la atribución en tu versión modificada.

**P: ¿Puedo usar Predator en competencias?**  
R: Sí, completamente. De hecho, fue diseñado para ello.

**P: ¿Puedo cambiar la licencia de mi derivado?**  
R: No, debe mantenerse la licencia de Código Abierto por Mención de Autor.

**P: ¿Qué pasa si violo la licencia?**  
R: La licencia puede ser terminada. Contacta a XpriT Robotics para resolver.

---

**Versión de Licencia**: 1.0  
**Última actualización**: Noviembre 20, 2025

*Predator Robot* © 2024-2025 **XpriT Robotics**

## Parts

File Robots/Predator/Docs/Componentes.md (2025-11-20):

# Lista de Componentes - Predator

## Bill of Materials (BOM)

| Componente | Cantidad | Link |
|---|---|---|
| Placa Xmotion | 1 | [https://www.jsumo.com/xmotion-robot-controller](https://www.jsumo.com/xmotion-robot-controller) |
| Motores Jsumo 750RPM | 2 | [https://www.jsumo.com/core-dc-motor-6v-750rpm](https://www.jsumo.com/core-dc-motor-6v-750rpm) |
| Sensores JS40F (IR Distance) | 4 | [https://www.jsumo.com/js40f-digital-infrared-ir-distance-sensor-min-40-cm-range](https://www.jsumo.com/js40f-digital-infrared-ir-distance-sensor-min-40-cm-range) |
| Ruedas JS2622 (Par) | 1 | [https://www.jsumo.com/js2622-aluminum-silicone-wheel-pair](https://www.jsumo.com/js2622-aluminum-silicone-wheel-pair) |
| Sensor de Línea ML1 | 2 | [https://www.jsumo.com/micro-line-sensor-ml1](https://www.jsumo.com/micro-line-sensor-ml1) |
| Batería Microstar 3S 350mAh | 1 | N/A |

## Notas

- **Placa Xmotion**: Controladora principal con soporte para Arduino Leonardo
- **Motores**: Motor DC 6V 750RPM para propulsión diferencial
- **Sensores JS40F**: Sensores IR para detección de oponentes (rango ~40cm)
- **Ruedas JS2622**: Par de ruedas de aluminio con silicona para tracción
- **Sensores ML1**: Sensores de línea para detección de bordes/acantilado
- **Batería**: LiPo 3S 350mAh 11.1V para alimentación del robot

## Proveedores

Todos los componentes están disponibles en:
- **JsumoRobots** (Proveedor principal): https://www.jsumo.com/

## Total Estimado

Costo total aproximado: Verificar en sitio del proveedor según disponibilidad y región.

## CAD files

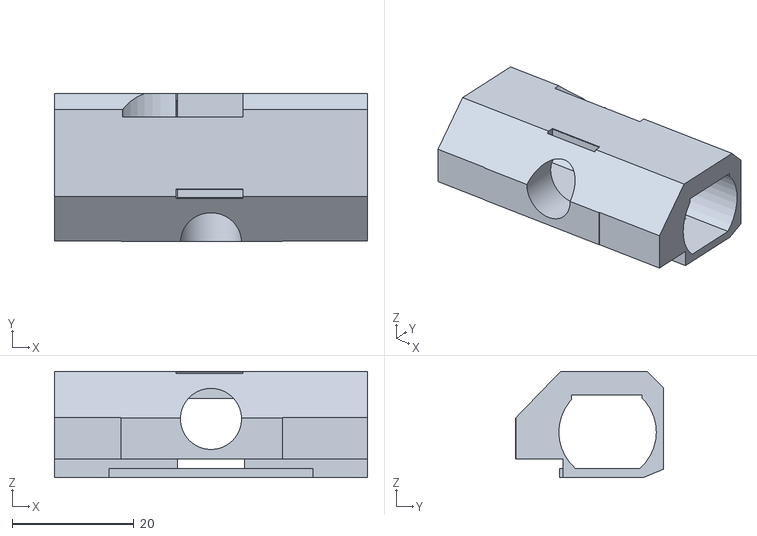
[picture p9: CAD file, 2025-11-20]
Robots/Predator/STL/bracket.stl
51.3 x 24.3 x 17.4

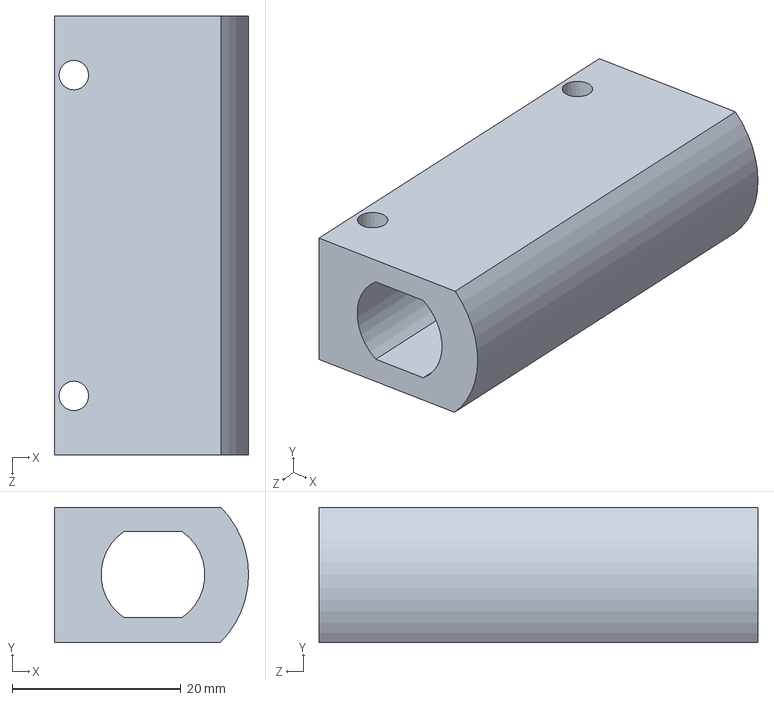
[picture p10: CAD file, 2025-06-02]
Robots/XT_Kaisei/SLDPRT/XTKaisei_Bracket-N20.SLDPRT
23.0 x 16.0 x 52.0 mm

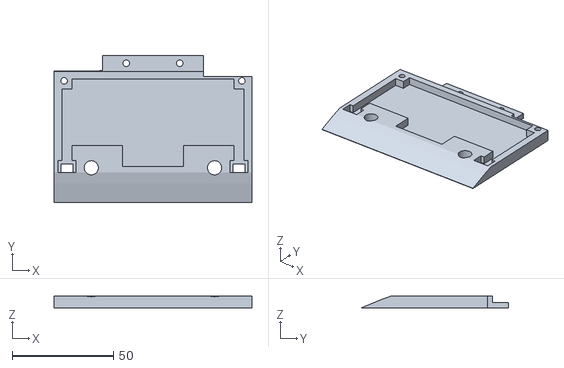
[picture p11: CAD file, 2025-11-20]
Robots/Predator/STL/base.stl
98.0 x 72.6 x 6.00

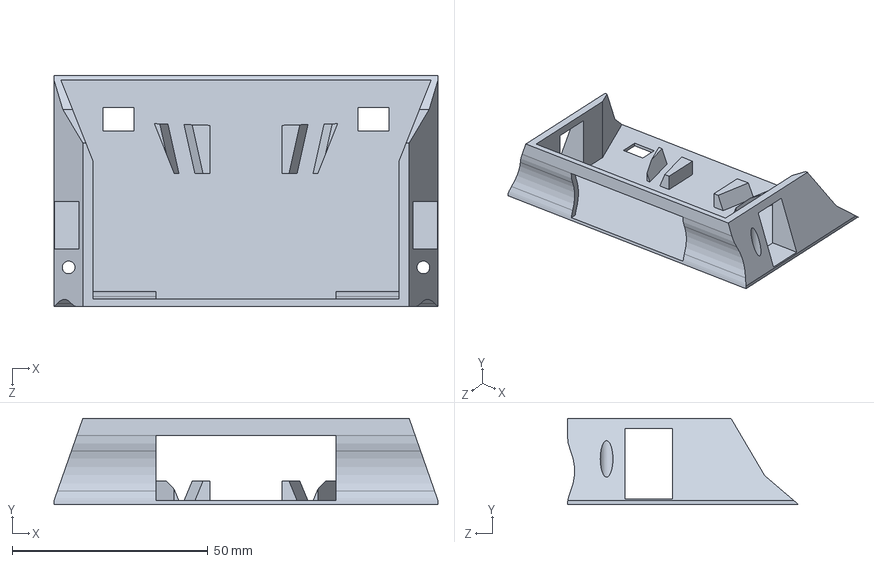
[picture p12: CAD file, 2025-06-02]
Robots/XT_Kaisei/SLDPRT/XTKaisei_Cuerpo.SLDPRT
98.0 x 22.0 x 59.0 mm

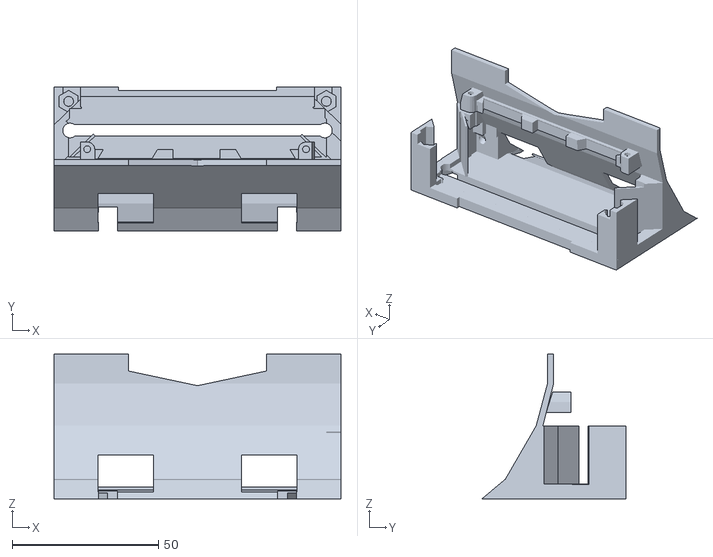
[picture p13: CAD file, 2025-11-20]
Robots/Predator/STL/chasis.stl
98.0 x 49.3 x 49.5

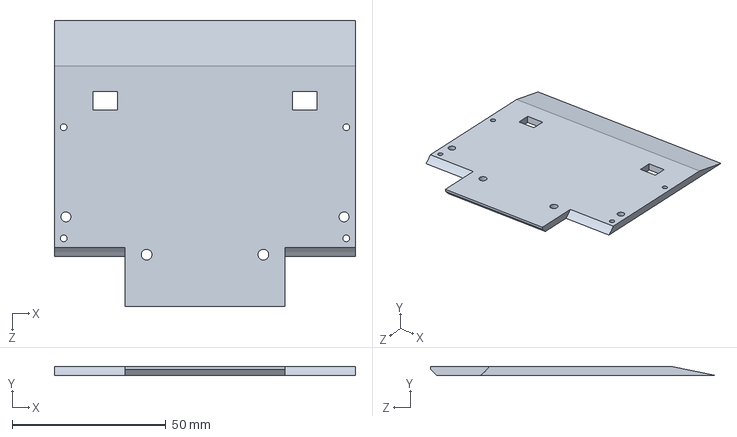
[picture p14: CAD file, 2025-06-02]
Robots/XT_Kaisei/SLDPRT/XTKaisei_Base.SLDPRT
98.0 x 3.00 x 93.0 mm

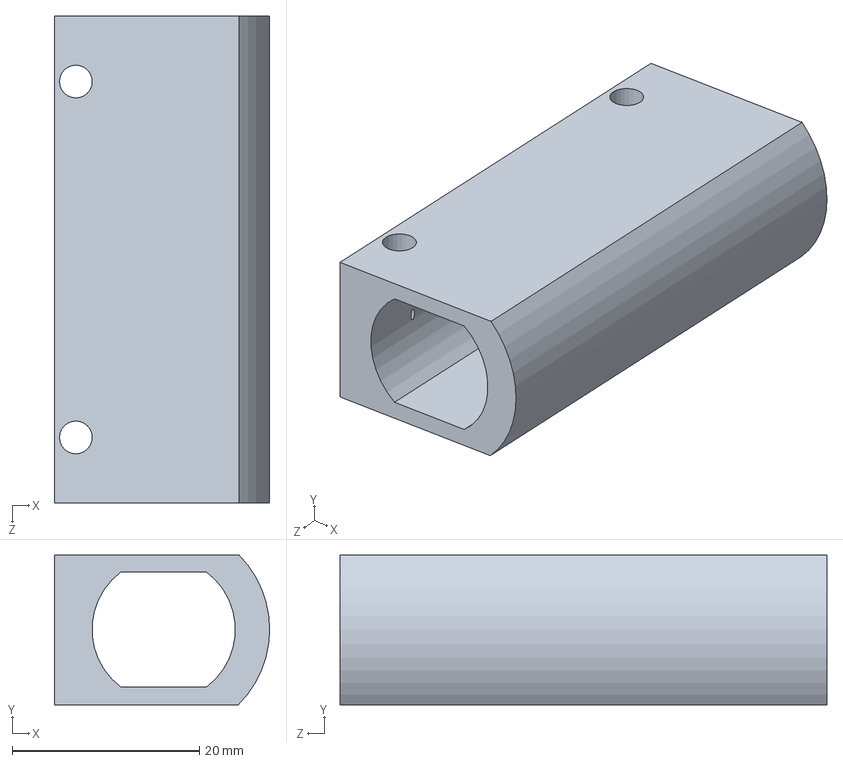
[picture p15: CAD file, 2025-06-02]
Robots/XT_Kaisei/SLDPRT/XTKaisei_Bracket.SLDPRT
23.0 x 16.0 x 52.0 mm

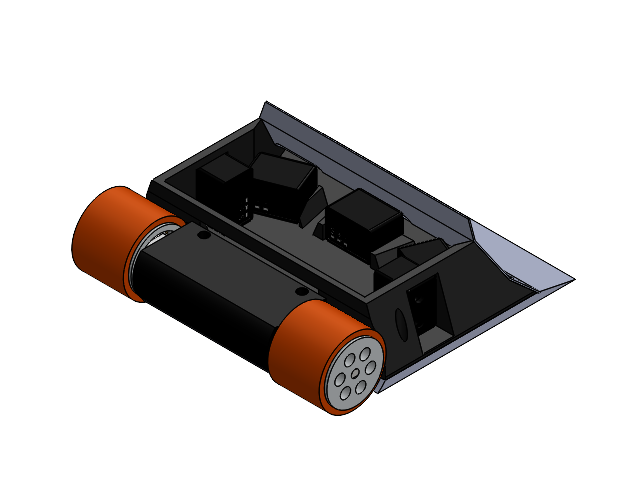
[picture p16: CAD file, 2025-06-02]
Robots/XT_Kaisei/SLDPRT/XTKaisei_Ensamblaje.SLDASM
XTKaisei_Base
XTKaisei_Bracket
XTKaisei_Cuerpo
JS2622 x 2
JSCoreMotor x 2
JS40F x 5
Pieza3^XTKaisei_Ensamblaje

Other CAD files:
Robots/XT_Kaisei/STL/XTKaisei_Base.STL
Robots/XT_Kaisei/STL/XTKaisei_Bracket-N20.STL
Robots/XT_Kaisei/STL/XTKaisei_Bracket.STL
Robots/XT_Kaisei/STL/XTKaisei_Cuerpo.STL

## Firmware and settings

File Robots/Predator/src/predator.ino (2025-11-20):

#include <xmotion.h>

// ====== Pines de Oponente (0 = detecta) ======
int RightSensor         = A2; // Derecha
int RightDiagonalSensor = A4; // Diagonal derecha
int LeftDiagonalSensor  = 2;  // Diagonal izquierda
int LeftSensor          = 1;  // Izquierda

// ====== Pines Sensores de Línea (analógicos) ======
int LeftLine  = A5; // Línea izquierda
int RightLine = A1; // Línea derecha

// ====== Botón y LEDs ======
const int StartPin   = 10; // INPUT_PULLUP
const int LedNaranja = 8;  // LED reposo
const int LedAzul    = 9;  // LED cuenta 5s

// ====== Parámetros ======
int velBusqueda = 30; // velocidad de búsqueda lenta (0..255)

// ====== Estado del sistema ======
enum Estado { IDLE, COUNTDOWN, RUN };
Estado estado = IDLE;

// ====== Antirrebote & clic ======
bool prevBtn = HIGH; // INPUT_PULLUP -> reposo en HIGH
bool btnStable = HIGH;
unsigned long lastDebounce = 0;
const unsigned long DEBOUNCE_MS = 30;

bool buttonClicked() {
  bool reading = digitalRead(StartPin);
  if (reading != btnStable && (millis() - lastDebounce) > DEBOUNCE_MS) {
    btnStable = reading;
    lastDebounce = millis();
    if (prevBtn == LOW && btnStable == HIGH) { // flanco de subida = clic
      prevBtn = btnStable;
      return true;
    }
    prevBtn = btnStable;
  }
  return false;
}

// ====== LEDs ======
void ledsReposo() { digitalWrite(LedNaranja, HIGH); digitalWrite(LedAzul, LOW); }
void ledsOff()    { digitalWrite(LedNaranja, LOW);  digitalWrite(LedAzul, LOW); }

void parpadearAzul(unsigned long msTot, unsigned long blinkMs = 250) {
  unsigned long t0 = millis();
  bool estado = false;
  while (millis() - t0 < msTot) {
    estado = !estado;
    digitalWrite(LedAzul, estado);
    delay(blinkMs);
  }
  digitalWrite(LedAzul, LOW);
}

// ====== Seguridad por línea ======
bool safetyLinea() {
  const int UMBRAL_LINEA = 700;  // ajustá a tu tatami
  int l = analogRead(LeftLine);
  int r = analogRead(RightLine);

  if (l < UMBRAL_LINEA && r > UMBRAL_LINEA) {
    xmotion.Backward(120, 100);
    xmotion.Right0(120, 100);
    return true;
  } else if (l > UMBRAL_LINEA && r < UMBRAL_LINEA) {
    xmotion.Backward(120, 100);
    xmotion.Left0(120, 100);
    return true;
  } else if (l < UMBRAL_LINEA && r < UMBRAL_LINEA) {
    xmotion.Backward(120, 100);
    xmotion.Right0(120, 100);
    return true;
  }
  return false;
}

void setup() {
  pinMode(LedNaranja, OUTPUT);
  pinMode(LedAzul, OUTPUT);
  pinMode(StartPin, INPUT_PULLUP);

  pinMode(RightSensor,         INPUT);
  pinMode(RightDiagonalSensor, INPUT);
  pinMode(LeftDiagonalSensor,  INPUT);
  pinMode(LeftSensor,          INPUT);

  pinMode(LeftLine,  INPUT);
  pinMode(RightLine, INPUT);

  Serial.begin(9600);
  xmotion.StopMotors(100);
  xmotion.MotorControl(0, 0);

  estado = IDLE;
  ledsReposo();
}

void loop() {
  // === Botón ===
  if (buttonClicked()) {
    if (estado == IDLE) {
      estado = COUNTDOWN;
    } else if (estado == RUN) {
      xmotion.MotorControl(0, 0);
      estado = IDLE;
      ledsReposo();
      return;
    }
  }

  // === Máquina de estados ===
  switch (estado) {
    case IDLE: {
      xmotion.MotorControl(0, 0); // inmóvil, naranja fijo
    } break;

    case COUNTDOWN: {
      digitalWrite(LedNaranja, LOW);
      parpadearAzul(5000, 250);   // 5 segundos
      estado = RUN;
      ledsOff();
    } break;

    case RUN: {
      // Seguridad línea
      if (safetyLinea()) return;

      // Lecturas de oponente
      int sR  = digitalRead(RightSensor);
      int sRD = digitalRead(RightDiagonalSensor);
      int sLD = digitalRead(LeftDiagonalSensor);
      int sL  = digitalRead(LeftSensor);

      // ====== Lógica de ataque con 4 sensores (0 = detecta) ======
      // Prioridades: detección bilateral -> frente; detección lateral -> giros; si no ve -> búsqueda lenta
      bool veDerecha = (sR == 1)  || (sRD == 0);
      bool veIzquierda = (sL == 1) || (sLD == 0);

      if (veDerecha && veIzquierda) {
        // Algo frente / ambos lados: atacar de frente
        xmotion.MotorControl(255, 255);
      }
      else if (veDerecha) {
        // Solo derecha: girar a la derecha (acercarse)
        if (sR == 0) {
          xmotion.MotorControl(-255, 255);   // giro fuerte derecha
        } else {
          xmotion.MotorControl(-100, 255);    // corrección suave derecha
        }
      }
      else if (veIzquierda) {
        // Solo izquierda: girar a la izquierda (acercarse)
        if (sL == 0) {
          xmotion.MotorControl(255, -255);   // giro fuerte izquierda
        } else {
          xmotion.MotorControl(255, -100);    // corrección suave izquierda
        }
      }
      else {
        // No ve a nadie: búsqueda lenta
        xmotion.MotorControl(velBusqueda, velBusqueda);
      }
    } break;
  }
}

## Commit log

2025-06-02 Kaisei v1 uploaded, readme and images
    [XTKaisei_Base.SLDPRT, XTKaisei_Base.STL, XTKaisei_Bracket.SLDPRT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]
2025-06-02 bracket n20 updated
    [XTKaisei_Bracket-N20.SLDPRT, XTKaisei_Bracket-N20.STL]
2025-11-20 Predator Added
    [base.stl, bracket.stl, chasis.stl]
